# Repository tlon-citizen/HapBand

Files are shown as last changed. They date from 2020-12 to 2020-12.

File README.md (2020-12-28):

# HapBand
<b>Wearable device to provide multimodal feedback</b>

HapBand is a wearable and wireless device composed of two modules to be worn in the upper arm. The modules are driven by an Espressif ESP32 dual-core microprocessor clocked at 240 Mhz with 520Kb RAM and powered by rechargeable 18650HG2 Li-Ion batteries (3.7V).
The modules-to-PC latency is approximately 30 ms.
Actuators and electrodes are connected to the modules with thin cables that can be comfortably accommodated along the arm.
The tactile module (116mm x 65mm x 15mm) provides tapping and vibration stimuli through a wearable fingertip (64mm x 32mm x 32mm).
Additionally, there is a TES/EMS module (116mm x 52mm x 25mm) providing tendon and muscle electrical stimulation. This module uses an off-the-shelf transcutaneous nerve stimulator (Schwa Medico Medizintechnik Art.-Nr. 104099-V08), the PCB and the firmware are based on the openEMSstim project by Pedro Lopes and Max Pfeiffer[1,2]. 
The TES/EMS module supports two channels (i.e., two muscles or tendons can be stimulated independently by two pairs of electrodes connected from the module to the selected arm muscles). For every channel, experiment operators can set the intensity and the duration of the electrical pulse.
The device case was 3d-printed with resin material and the total weight is 31 grams. 
The fingertip wearable is mechanically connected by electromagnetic solenoids. The top push-pull solenoid provides a tapping sensation on the fingertip and the front solenoid provides soft touches on the finger pulp. The vibration sensations on the fingertip are provided with a piezo actuator measuring 35mm x 4mm x 4mm (Samsung PHAH353832XX, 120Vpp AC, sine wave @230Hz) which is controlled by a haptic driver (Texas Instruments DRV2667 by the I2C protocol). 
The piezo element touches the fingertip whenever the top solenoid is closed.




This repository contains the necessary files to build a new device; model files for 3D printing, schematics for electronics, and embedded/testing code.



A Unity plugin manages all the sensors and actuators connected to the HapBand modules. In addition to UI for controlling/enabling sensations, the plugin also presents real-time information regarding the wireless connection, as well as, debugging information from pressure sensors (up to two) and capacitive pins (up to 8, used for input interaction in VEs). The plugin also manages the wireless connection with the TES/EMS module and safely keeps the parameters under the clinical limits established by the analog nerve stimulator.



[1]https://github.com/PedroLopes/openEMSstim/<br>
[2]https://bitbucket.org/MaxPfeiffer/letyourbodymove/wiki/Home

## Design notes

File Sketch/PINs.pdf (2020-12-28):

# HapFingers output pins

L

R
Solenoid 1 ⊖

Solenoid 2 ⊕

Solenoid 1 ⊕
Solenoid 2 ⊖

Piezo ⊕
Piezo ⊖
Haptic Reactor 1 ⊕
Haptic Reactor 1 ⊖
Haptic Reactor 2 ⊖
Haptic Reactor 2 ⊕
Pressure Sensor 1 ⊕
Pressure Sensor 1 ⊖
Pressure Sensor 2 ⊕
Pressure Sensor 2 ⊖
Solenoid 3 ⊖
Solenoid 3 ⊕
Capacitive pin 1
Capacitive pin 2
Capacitive pin 3
Capacitive pin 4
Capacitive pin 5
Capacitive pin 6
Capacitive pin 7
Capacitive pin 8

# HapEMSG output pins

L

R
Channel 1 EMS Unit | ⊕
Channel 1 EMS Unit | ⊖

Channel 1 Electrode ⊕
Channel 1 Electrode ⊖

Channel 2 EMS Unit ⊕
Channel 2 Electrode ⊕
Channel 2 Electrode ⊖
Channel 2 EMS Unit ⊖
No Signal
EMG Sensor ⊕
EMG Sensor ⊖
EMG Sensor Data

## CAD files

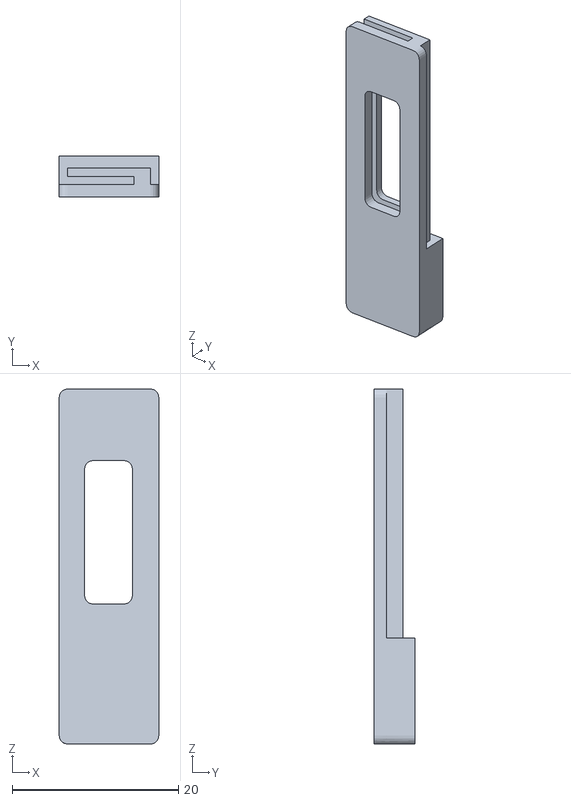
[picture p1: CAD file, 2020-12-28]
3DModel/HapFingers-Index/TopSliderHR.stl
12.0 x 4.95 x 42.8

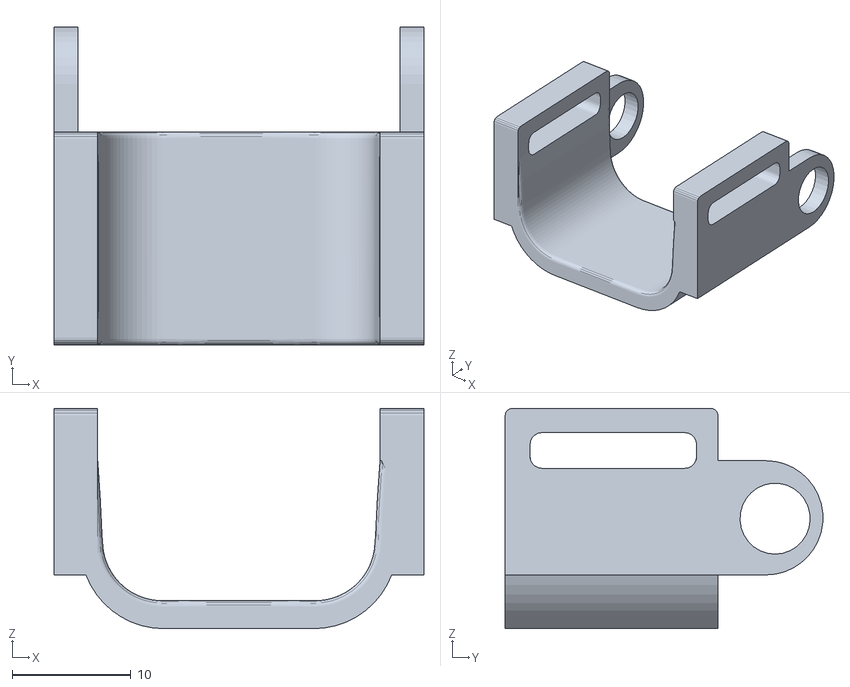
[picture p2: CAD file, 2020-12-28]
3DModel/HapFingers-Thumb/FingerTipSupport.stl
31.1 x 26.7 x 18.5

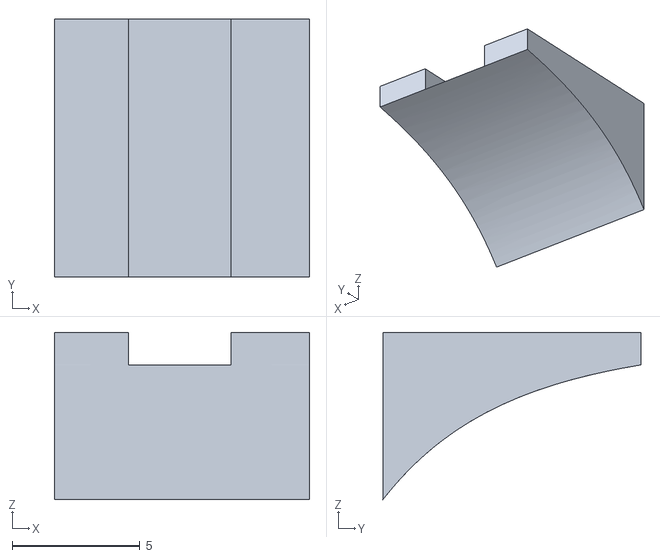
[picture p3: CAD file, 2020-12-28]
3DModel/HapFingers-Index/RampPiezo.stl
10.0 x 10.1 x 6.55

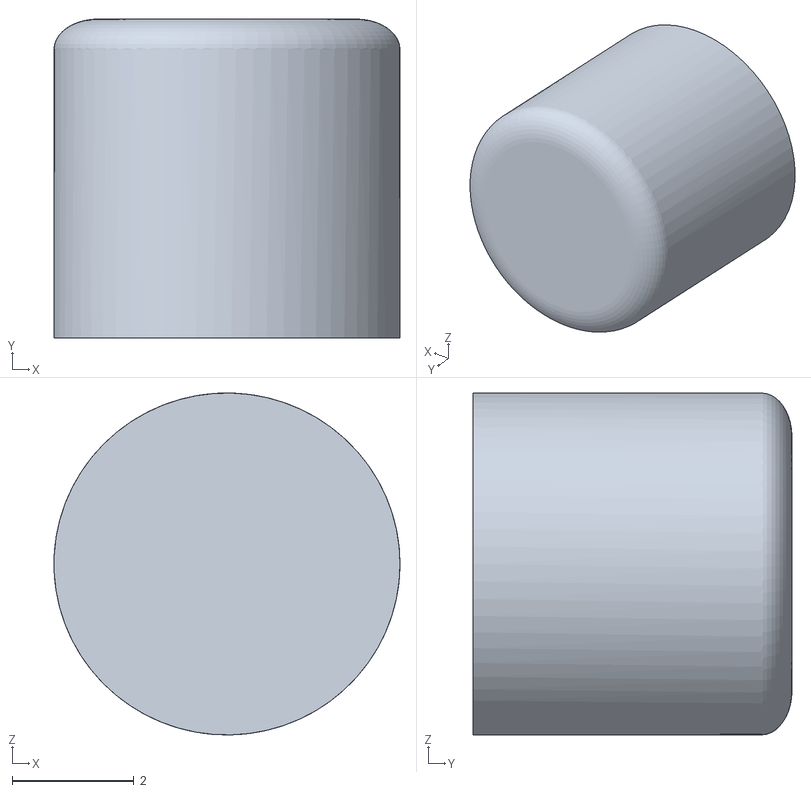
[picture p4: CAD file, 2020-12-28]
3DModel/HapFingers-Thumb/Axis A.stl
5.70 x 5.25 x 5.63

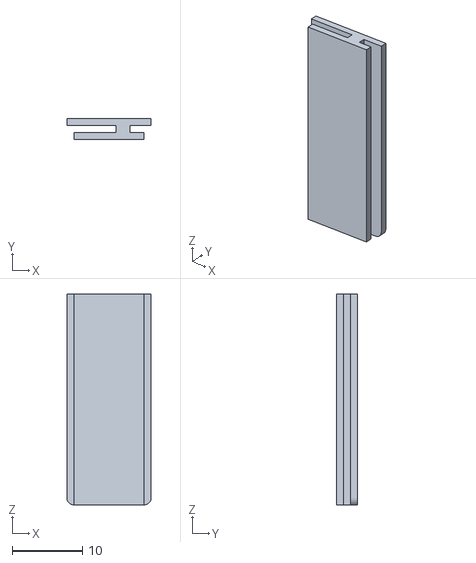
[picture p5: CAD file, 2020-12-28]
3DModel/HapFingers-Index/TopSlider.stl
12.0 x 3.00 x 30.0

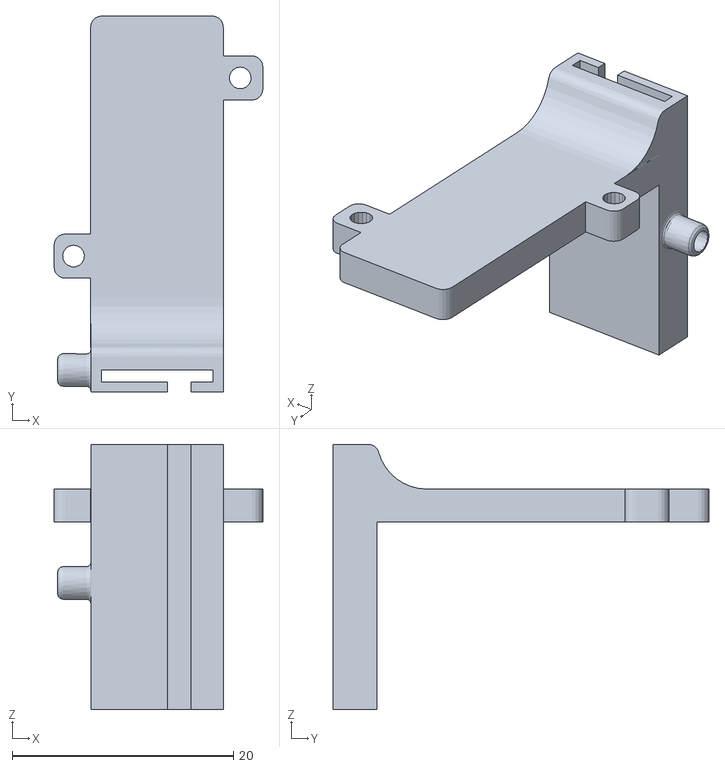
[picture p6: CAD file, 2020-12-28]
3DModel/HapFingers-Thumb/LSlider.stl
18.9 x 34.0 x 24.0

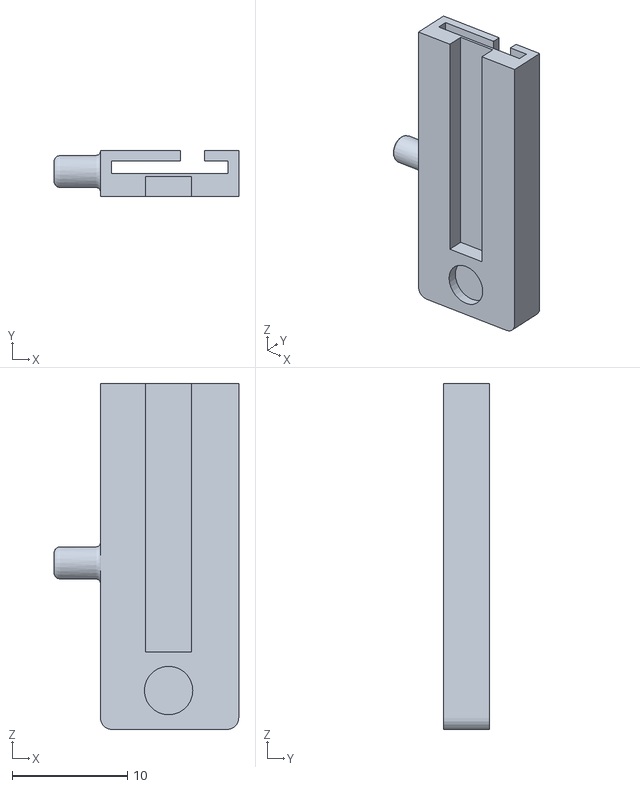
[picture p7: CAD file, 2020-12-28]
3DModel/HapFingers-Index/BottomSliderFront.stl
16.0 x 4.00 x 30.0

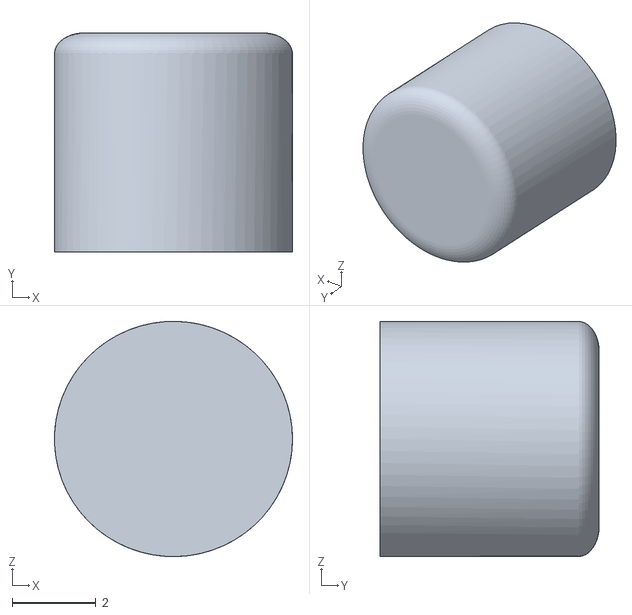
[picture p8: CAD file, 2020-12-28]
3DModel/HapFingers-Thumb/Axis B.stl
5.70 x 5.25 x 5.63

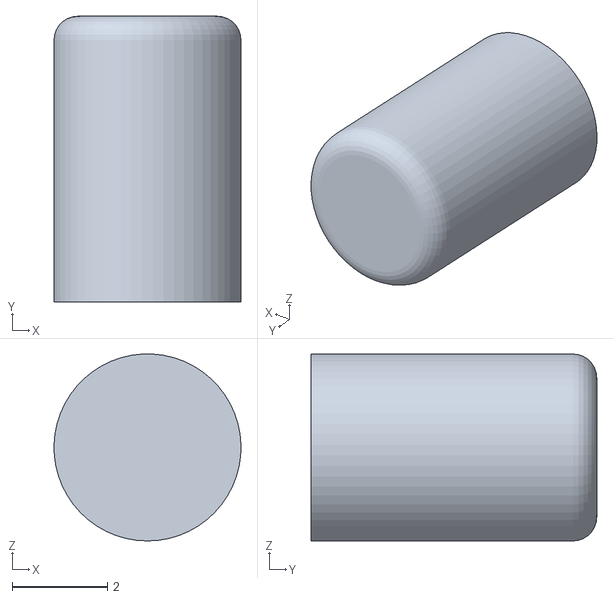
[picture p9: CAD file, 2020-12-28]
3DModel/HapFingers-Index/Axis A.stl
3.93 x 6.00 x 3.93

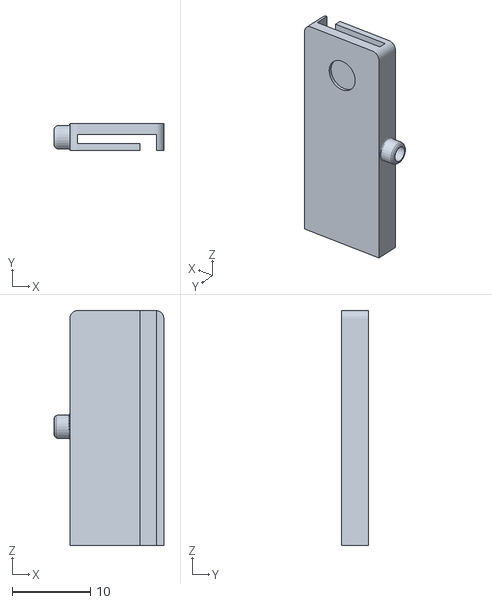
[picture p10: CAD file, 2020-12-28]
3DModel/HapFingers-Thumb/BottomSliderHR.stl
14.0 x 3.40 x 30.0

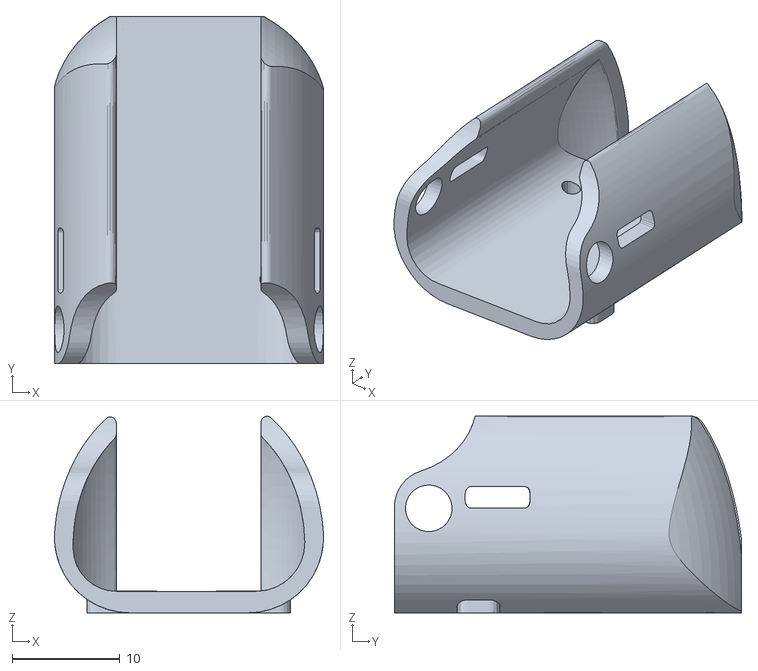
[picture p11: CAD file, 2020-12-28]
3DModel/HapFingers-Index/FingerTip.stl
25.0 x 32.2 x 18.2

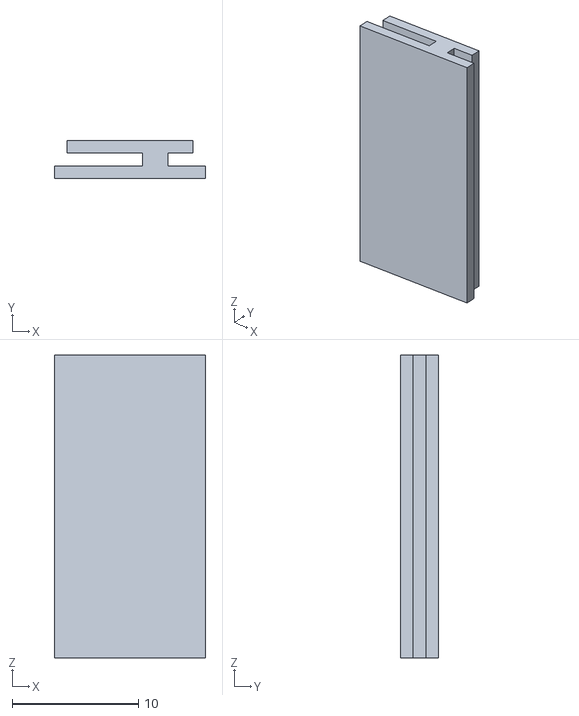
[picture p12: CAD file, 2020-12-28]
3DModel/HapFingers-Thumb/TopSliderFront.stl
12.0 x 3.00 x 24.0

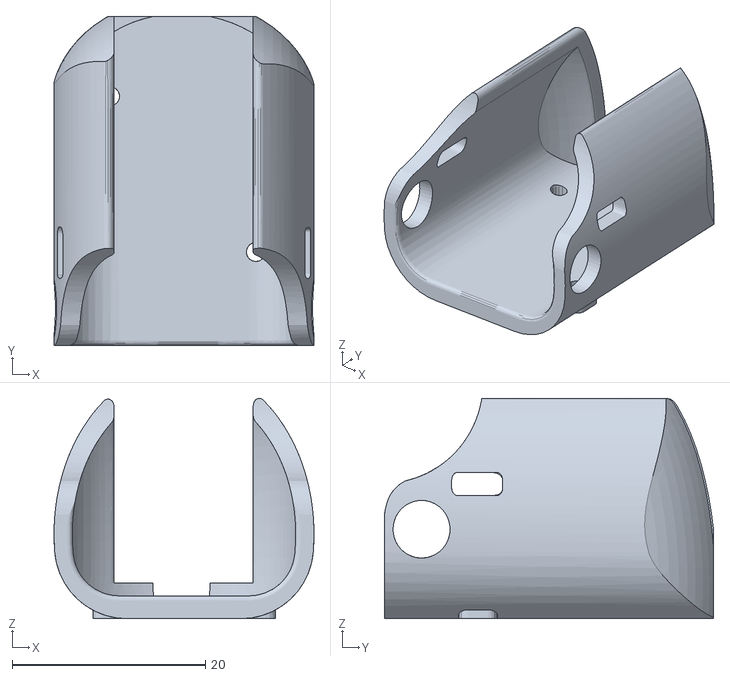
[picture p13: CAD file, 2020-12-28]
3DModel/HapFingers-Thumb/FingerTip.stl
26.9 x 34.0 x 22.8

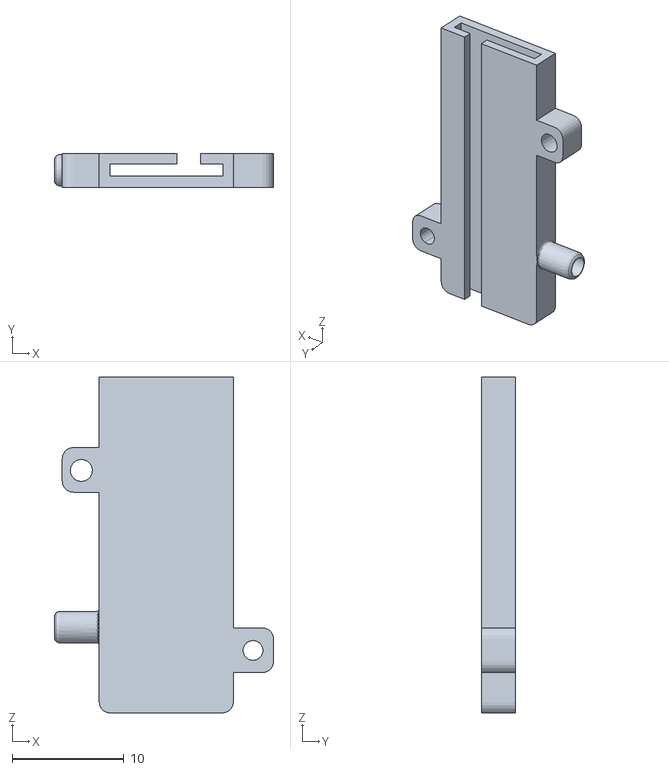
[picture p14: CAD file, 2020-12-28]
3DModel/HapFingers-Index/BottomSlider.stl
19.6 x 3.00 x 30.0

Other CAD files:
3DModel/HapFingers-Index/TopSliderFront.stl
3DModel/HapFingers-Thumb/TopSliderHR.stl
3DModel/HapFingers-Index/FingerTipSupport.stl
3DModel/HapFingers-Index/BottomSliderHR.stl
3DModel/HapFingers-Index/Axis B.stl
3DModel/HapFingers-Index/RampHR.stl

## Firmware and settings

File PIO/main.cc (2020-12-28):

#include <Arduino.h>
#include <Stream.h>
#include <assert.h>
#include "soc/rmt_struct.h"
#include "esp32-hal.h"
#include "esp_intr.h"
#include "driver/gpio.h"
#include "driver/periph_ctrl.h"
#include "freertos/semphr.h"

#include <TDSugar.h>
#include <TDESP32Pins.h>
#include <TDStreamFactory.h>
#include <TDComponent.h>
#include <TDSensor.h>
#include <TDTimer.h>
#include <TDTools.h>
#include <TDSPISlave.h>
#include <TDBusManager.h>
#include <TDI2CSwitch.h>
#include <TDHDRV2667.h>
#include <TDHDRV2605.h>
#include "SDUtilities.h"
#include "WiFiManager.h"
#include "AudioManager.h"
#include <TDCAP1188.h>

#define solenoid_1 12
#define solenoid_2 27
#define solenoid_3 33

#define pressureSensor_1 A3
#define pressureSensor_2 A4

char PV1 = 0;
char PV2 = 0;

unsigned long startTime;
unsigned long endTime;
int incomingChar;

TDHDRV2667 *hDRV2667;

WiFiManager *_WiFiManager;
AudioManager *_AudioManager;

TDCAP1188 * _Cap1188;

Stream *outputStream;

SPIClass _SPI(VSPI);

bool notificationEnabled = !true;
unsigned long notificationTimer = 0;

void WiFiTask(void *args);

class GeneralCommandHandler: public WiFiRemoteCommandHandler
{
  public:
    bool onCommand(String command)
    {
        if(strncmp(command.c_str(), "SE1", 3) == 0)
        {
            digitalWrite(solenoid_1, HIGH);
            if(ACTUATORS_DEBUG) Serial.println("Solenoid 1 On");
            return true;
        }
        else if(strncmp(command.c_str(), "SD1", 3) == 0)
        {
            digitalWrite(solenoid_1, LOW);
            if(ACTUATORS_DEBUG) Serial.println("Solenoid 1 Off");
            return true;
        }
        else if(strncmp(command.c_str(), "SE2", 3) == 0)
        {
            digitalWrite(solenoid_2, HIGH);
            if(ACTUATORS_DEBUG) Serial.println("Solenoid 2 On");
            return true;
        }
        else if(strncmp(command.c_str(), "SD2", 3) == 0)
        {
            digitalWrite(solenoid_2, LOW);
            if(ACTUATORS_DEBUG) Serial.println("Solenoid 2 Off");
            return true;
        }
        else if(strncmp(command.c_str(), "SE3", 3) == 0)
        {
            digitalWrite(solenoid_3, HIGH);
            if(ACTUATORS_DEBUG) Serial.println("Solenoid 3 On");
            return true;
        }
        else if(strncmp(command.c_str(), "SD3", 3) == 0)
        {
            digitalWrite(solenoid_3, LOW);
            if(ACTUATORS_DEBUG) Serial.println("Solenoid 3 Off");
            return true;
        }
        else if(strncmp(command.c_str(), "NED", 3) == 0) // Notifications enable/disable
        {
            parameter = atoi(&(command.c_str()[3]));
            notificationEnabled = (parameter == 1);
            if(ACTUATORS_DEBUG){ Serial.print("Notifications enabled : ");Serial.println(notificationEnabled); }
            return true;
        }

        return false;
    };

    private:
    byte parameter;
};

void setup()
{
    startTime = millis();

    pinMode(led, OUTPUT);
    pinMode(solenoid_1, OUTPUT);
    pinMode(solenoid_2, OUTPUT);
    pinMode(solenoid_3, OUTPUT);
    pinMode(pressureSensor_1, INPUT);
    pinMode(pressureSensor_2, INPUT);

    outputStream = TDStreamFactory::getHWSerialStream(MONITOR_SPEED);
    Serial.println("");
    Serial.println("Starting...");

    TDBusManager::initSPI(&_SPI);
	
	SDUtilities::init();
    
    TDBusManager::initI2C(
        I2C_NUM_0, 
        TD_ESP32_I2C_SDA_PIN, 
        TD_ESP32_I2C_SCL_PIN, 
        ESP32_I2C_FREQUENCY, 
        ESP32_I2C_RX_BUFFER_SIZE, 
        ESP32_I2C_TX_BUFFER_SIZE
    );
    
    ///////////////////////////////////////////////////////////////////////////////////

    //btStop(); // Disable BLE
    _WiFiManager = new WiFiManager("WiFi manager for wireless multi-device support", "WiFi Manager");

    ///////////////////////////////////////////////////////////////////////////////////

    _AudioManager = new AudioManager("Audio manager with I2S support", "Audio Manager", _WiFiManager);
    short mode = AUDIO_MANAGER_MODE_TWO_PORTS_EXTERNAL_I2S;
    _AudioManager->init(mode);

    ///////////////////////////////////////////////////////////////////////////////////

    hDRV2667 = new TDHDRV2667("Haptic Piezo Driver DRV2667", "Haptic DRV2667", _WiFiManager);    
    hDRV2667->init();

    ///////////////////////////////////////////////////////////////////////////////////

    _Cap1188 = new TDCAP1188("Capacitive Sensor CAP1188", "CAP1188", _WiFiManager);
    _Cap1188->init();
    
    ///////////////////////////////////////////////////////////////////////////////////

    _WiFiManager->addRemoteCommandHandler(new GeneralCommandHandler());
    _WiFiManager->addRemoteCommandHandler(new DRV2667CommandHandler(hDRV2667));
    _WiFiManager->addRemoteCommandHandler(new AudioCommandHandler(_AudioManager));

    ///////////////////////////////////////////////////////////////////////////////////

    TaskHandle_t WiFiTaskHandle;
    xTaskCreate(WiFiTask,            // function to run
                "WiFi Task",         // human readable desc
                10 * 1024,           // reserved stack size ///
                NULL,                // parameters
                2,                   // uxPriority
                &WiFiTaskHandle);    // task handle

    ///////////////////////////////////////////////////////////////////////////////////

    endTime = millis();
    LogPrint(F("Loading time (ms): "));
    LogPrintln((int)(endTime - startTime));

    LogPrintln(F("HapBand is ready!"));
    ShowLedSequenceD();

    hDRV2667->play(130,((255*660)/1992),100,1);
    delay(150);
    hDRV2667->play(130,((255*660)/1992),100,1);
    delay(300);
    hDRV2667->play(130,((255*660)/1992),100,1);
    delay(300);
    hDRV2667->play(130,((255*510)/1992),100,1);
    delay(100);
    hDRV2667->play(130,((255*660)/1992),100,1);
    delay(300);
    hDRV2667->play(130,((255*770)/1992),100,1);
    delay(550);
    //hDRV2667->play(230,((255*380)/1992),100,1);
    //delay(1000);

    
    /*
    hDRV2667->play(250,128,50,1);
    delay(25);
    hDRV2667->play(250,1166,250,3);
    delay(500);
    */
    
    /*
    hDRV2667->play(230,135,250,1);
    delay(250);
    hDRV2667->play(230,195,250,1);
    delay(150);
    hDRV2667->play(230,235,250,1);
    delay(250);
    hDRV2667->stop();
    */

    digitalWrite(solenoid_1, HIGH);
    delay(100);
    digitalWrite(solenoid_1, LOW);
    digitalWrite(solenoid_2, HIGH);
    delay(100);
    digitalWrite(solenoid_2, LOW);
    digitalWrite(solenoid_3, HIGH);
    delay(100);
    digitalWrite(solenoid_3, LOW);

    delay(500);

    _AudioManager->playNextA();
    _AudioManager->playNextB();
    delay(500);
    _AudioManager->playNextA();
    _AudioManager->playNextB();
    delay(500);
}

void processSerialInput()
{
    if (outputStream->available())
    {
        incomingChar = outputStream->read();
        
        if (incomingChar == '1')
        {
            //hDRV2667->play(100,400,250,2);
            hDRV2667->play(230,235,250,1);
        }
        else if (incomingChar == '2')
        {
            hDRV2667->stop();
        }
        else if (incomingChar == 'i')
        {
            digitalWrite(solenoid_1, HIGH);
            delay(100);
            digitalWrite(solenoid_1, LOW);
            Serial.println("Solenoid1 On/Off");
        }
        else if (incomingChar == 'o')
        {
            digitalWrite(solenoid_2, HIGH);
            delay(100);
            digitalWrite(solenoid_2, LOW);
            Serial.println("Solenoid2 On/Off");
        }
        else if (incomingChar == 'p')
        {
            digitalWrite(solenoid_3, HIGH);
            delay(100);
            digitalWrite(solenoid_3, LOW);
            Serial.println("Solenoid3 On/Off");
        }
        else if (incomingChar == 'a')
        {
           _AudioManager->playNextA();
           _AudioManager->playNextB();
        }
        else if (incomingChar == 's')
        {
            _AudioManager->playA(4, 5, false);
            _AudioManager->playB(4, 5, false);
        }
        else if (incomingChar == 'd')
        {
            _AudioManager->playA(4, 30, false);
            _AudioManager->playB(4, 30, false);
        }
        else if (incomingChar == 'f')
        {
            _AudioManager->playA(4, 70, false);
            _AudioManager->playB(4, 70, false);
        }
        else if (incomingChar == 'g')
        {
            _AudioManager->playA(4, 100, false);
            _AudioManager->playB(4, 100, false);
        }
        else if (incomingChar == 'h')
        {
            _AudioManager->stopA();
            _AudioManager->stopB();
        }
    }
}

void sendNotifications()
{
    if (_WiFiManager->isClientConnected())
    {
        if(notificationEnabled && (millis() - notificationTimer) > 20) // ms >>> 40 = 25FPS
        {
            notificationTimer = millis();
            
            PV1 = analogRead(pressureSensor_1); 
            PV2 = analogRead(pressureSensor_2); 
            // map(analogRead(pressureSensor1), 0, 4000, 0, 255);
            //if(PV1 >=  1 | PV2 >= 1 ) Serial.println("P1 = " + String((int)PV1) + " P2 = " + String((int)PV2));

            _WiFiManager->sendData("N" + String((int)PV1) + "," + String((int)PV2) + "," + String((int)_Cap1188->getStatus()) + "#");
        }
    }   
}

void WiFiTask(void *args)
{
    while (TRUE)
    {
        _WiFiManager->loop();    

        delay(1); // DO NOT DELETE!!!!!
    }
}

void loop()
{
    //vTaskDelete(null);
    
    //if (!_WiFiManager->isClientConnected()) _AudioManager->loop();
    _AudioManager->loop();

    _Cap1188->loop();

    sendNotifications(); // pressure and capacitive sensors together

    processSerialInput();

    delay(1); // DO NOT DELETE!!!!!
}

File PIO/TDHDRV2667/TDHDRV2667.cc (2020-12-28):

#include <TDHDRV2667.h>

TDHDRV2667::TDHDRV2667 ( const char *argLongDesc, const char* argShortDesc, WiFiManager* _WiFiManager, TDI2CSwitch* argI2CSwitch, uint8_t address ) :
              TDComponent ( argLongDesc, argShortDesc, TDCOMPONENT_CONNECTION_BUILTIN ), TDI2CSlave ( address )
{
    this->_WiFiManager = _WiFiManager;
    i2CSwitch = argI2CSwitch;
}

TDHDRV2667::TDHDRV2667 ( const char *argLongDesc, const char* argShortDesc, WiFiManager* _WiFiManager, uint8_t address ) :
              TDComponent ( argLongDesc, argShortDesc, TDCOMPONENT_CONNECTION_BUILTIN ), TDI2CSlave ( address )
{
    this->_WiFiManager = _WiFiManager;
}

void TDHDRV2667::init(uint8_t index)
{
    if(index > 0) i2CSwitch->on(index);
  	    i2cWriteRegister8Data8(0x02, 0x00); //Take device out of standby mode
        LogPrint(F("DRV2667 "));
        if(index > 0) 
        {
            LogPrint(F("with index "));
            LogPrint(index);
        }
        LogPrintln(F(" started!"));
	if(index > 0) i2CSwitch->off(index);
}

// https://github.com/yurikleb/DRV2667
// WaveForm Array: [Amplitude, Freq, Cycles, Envelope]
// Amplitude    --  min:0=50v max: 255=100v
// Frequency    --  (0-255) >>> (7.8125-1992.1875)Hz
// Duration     --  Cycles 0-255
// Envelope     --  Ramp up + down
void TDHDRV2667::play(uint8_t amplitude, uint8_t frequency, uint8_t cycles, uint8_t envelope, uint8_t index)
{
    if(DRV2667Debug)
    {
        LogPrint(F("Piezo >> "));
        if(index > 0) LogPrint(F(" Index: "));     LogPrint(index);
        LogPrint(F(" Amplitude: ")); LogPrint(amplitude);
        LogPrint(F(" Frequency: ")); LogPrint((float)(frequency*7.8125)); LogPrint(F("Hz"));
        LogPrint(F(" Cycles: "));    LogPrint(cycles);
        LogPrint(F(" Envelope: "));  LogPrintln(envelope);
    }

    if(index > 0) i2CSwitch->on(index);
        //control
        i2cWriteRegister8Data8(0x02, 0x00); //Take device out of standby mode
        i2cWriteRegister8Data8(0x01, 0x03); //Set Gain 0-3 (0x00-0x03 25v-100v)
        i2cWriteRegister8Data8(0x03, 0x01); //Set sequencer to play WaveForm ID #1
        i2cWriteRegister8Data8(0x04, 0x00); //End of sequence
        //header
        i2cWriteRegister8Data8(0xFF, 0x01); //Set memory to page 1
        i2cWriteRegister8Data8(0x00, 0x05); //Header size -1
        i2cWriteRegister8Data8(0x01, 0x80); //Start address upper uint8_t (page), also indicates Mode 3
        i2cWriteRegister8Data8(0x02, 0x06); //Start address lower uint8_t (in page address)
        i2cWriteRegister8Data8(0x03, 0x00); //Stop address upper uint8_t
        i2cWriteRegister8Data8(0x04, 0x06+3); //Stop address Lower uint8_t // 3 = sizeof(WaveForm)-1
        i2cWriteRegister8Data8(0x05, 0x01); //Repeat count, play WaveForm once
        //WaveForm Data From the array
        i2cWriteRegister8Data8(0x06+0, amplitude);
        i2cWriteRegister8Data8(0x06+1, frequency);
        i2cWriteRegister8Data8(0x06+2, cycles);
        i2cWriteRegister8Data8(0x06+3, envelope);
        //Control
        i2cWriteRegister8Data8(0xFF, 0x00); //Set page register to control space
        i2cWriteRegister8Data8(0x02, 0x01); //Set GO bit (execute WaveForm sequence)
    if(index > 0) i2CSwitch->off(index);
}

void TDHDRV2667::stop(uint8_t index)
{
    if(index > 0) i2CSwitch->on(index);
	      i2cWriteRegister8Data8(0x02, 0x00); //Take device out of standby mode
    if(index > 0) i2CSwitch->off(index);

    if(DRV2667Debug) LogPrintln(F("Piezo >> Stop"));
}

void TDHDRV2667::setAnalogInput(uint8_t index)
{
	if(index > 0) i2CSwitch->on(index);
	    i2cWriteRegister8Data8(0x02, 0x00); //Take device out of standby mode
        i2cWriteRegister8Data8(0x01, 0x07); //Set to analog input + Gain 0-3 (0x04-0x07 25v-100v)
        i2cWriteRegister8Data8(0x02, 0x02); //Set EN_OVERRIDE bit = boost and amplifier active
	if(index > 0) i2CSwitch->off(index);
}

void TDHDRV2667::loop()
{
    /*
    i2CSwitch->on(index);
        if(DRV2667Debug)
        {
          LogPrintln(F(""));
        }
    i2CSwitch->off(index);
    */
}

void TDHDRV2667::parseArray(String buffer, byte preffixLength)
{
    String s = buffer.substring(preffixLength);
    char* ptr = NULL;
    char * b = new char [s.length()+1];
    strcpy(b, s.c_str());
    ptr = strtok(b, ",");  // list of delimiters
    piezoIndex = atoi(ptr); ptr = strtok(NULL, ",");
    amplitude = atoi(ptr); ptr = strtok(NULL, ",");
    frequency = atoi(ptr); ptr = strtok(NULL, ",");
    cycles    = atoi(ptr); ptr = strtok(NULL, ",");
    envelope  = atoi(ptr);
    play(amplitude, frequency, cycles, envelope, piezoIndex);
}

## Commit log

2020-12-28 1st commit
    [Axis A.stl, Axis B.stl, BottomSlider.stl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]
2020-12-28 Device picture updated
